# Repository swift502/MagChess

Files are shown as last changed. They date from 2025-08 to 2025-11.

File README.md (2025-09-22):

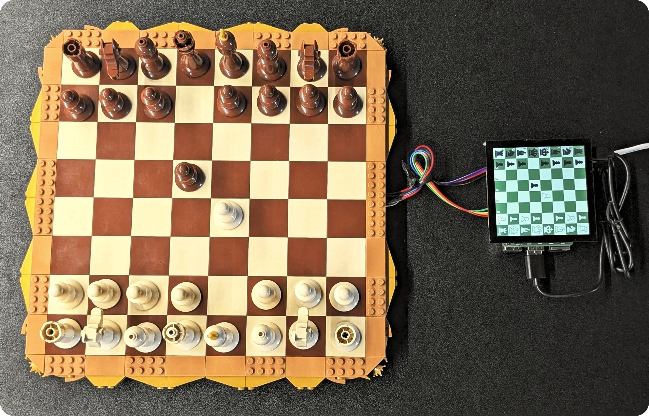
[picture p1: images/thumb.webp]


# MagChess

Magnetic chess game interpreter and PGN exporter for the Lego [Traditional Chess Set](https://www.lego.com/en-cz/product/traditional-chess-set-40719). Python app for the Raspberry Pi, and an Astro website to serve the results and show a leaderboard.

## App

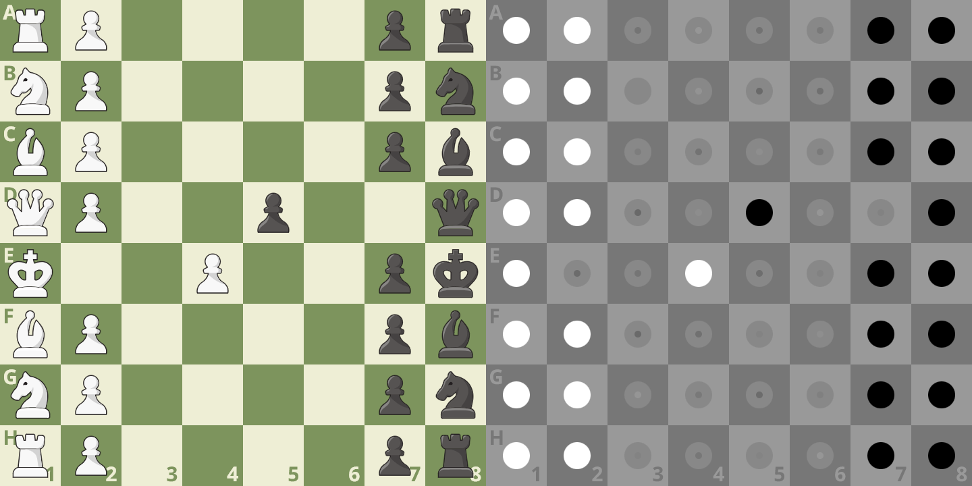
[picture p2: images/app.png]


**Setup:**

```bash
rpi_install.sh
```

After installation, a reboot is required for the I2C data rate change to take effect.

**Run:**

```bash
rpi_run.sh
```

### Desktop shortcut

```ini
[Desktop Entry]
Type=Application
Name=MagChess
Icon=/home/pi/Documents/Github/MagChess/app/assets/icon.ico
Exec=/home/pi/Documents/Github/MagChess/app/rpi_run.sh
Category=Game
```

### Autostart config

```bash
mkdir -p ~/.config/autostart
nano ~/.config/autostart/magchess.desktop
```

## Hardware

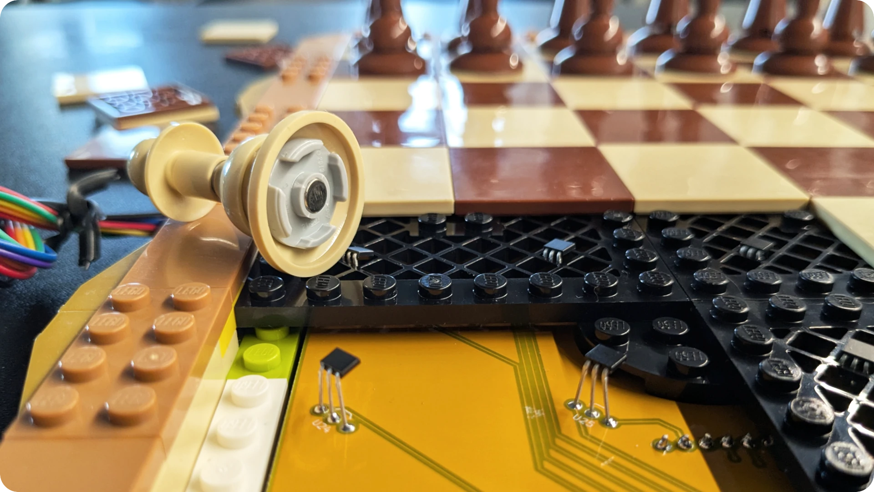
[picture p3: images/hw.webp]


The PCB in `kicad/pcb` is designed to fit a modified underside of the lego chessboard construction found in `bricklink_studio/chessboard.io`.

The PCB needs the following components soldered onto it:

- 64x SS49E
- 4x CD74HC4067
- ADS1015
- MP1584EN

Each lego chess piece has to be fitted with a magnet on the bottom. Round 5x2mm magnets happen to fit perfectly into the bottom of each piece.

Magnet polarity is important, if white pieces read magnetic north, black pieces should be flipped and read south. The hall sensors will then read colors as positive/negative voltage, which gives the app enough information to interpret chess moves correctly.

The app should be installed on a Raspberry Pi. The chessboard draws 5V and GND from the pi. Data pins are the I2C SDA and SCL pins and four mux selection pins, by default D21, D20, D16 and D12. An estimated 800mA is drawn by the hall sensors when powered.

## Scoreboard

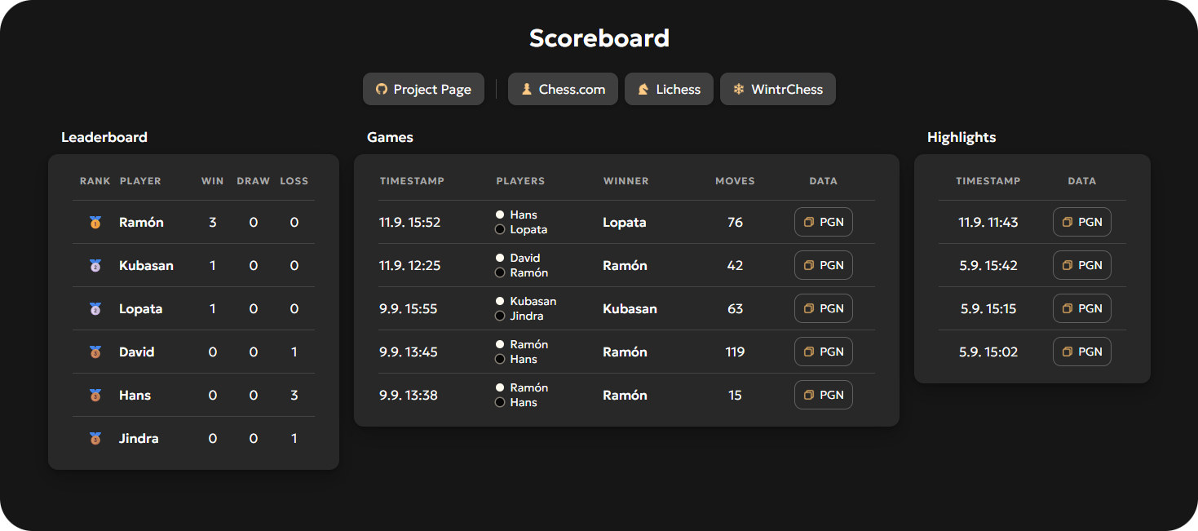
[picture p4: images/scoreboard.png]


<div align="center">
    <a href="https://swift502.github.io/MagChess">https://swift502.github.io/MagChess</a>
</div>
<br>

Astro website showing a leaderboard and a PGN archive. Deployed via GitHub Pages.

### Build notes

```bash
npm install
npm run dev
npm run build
```

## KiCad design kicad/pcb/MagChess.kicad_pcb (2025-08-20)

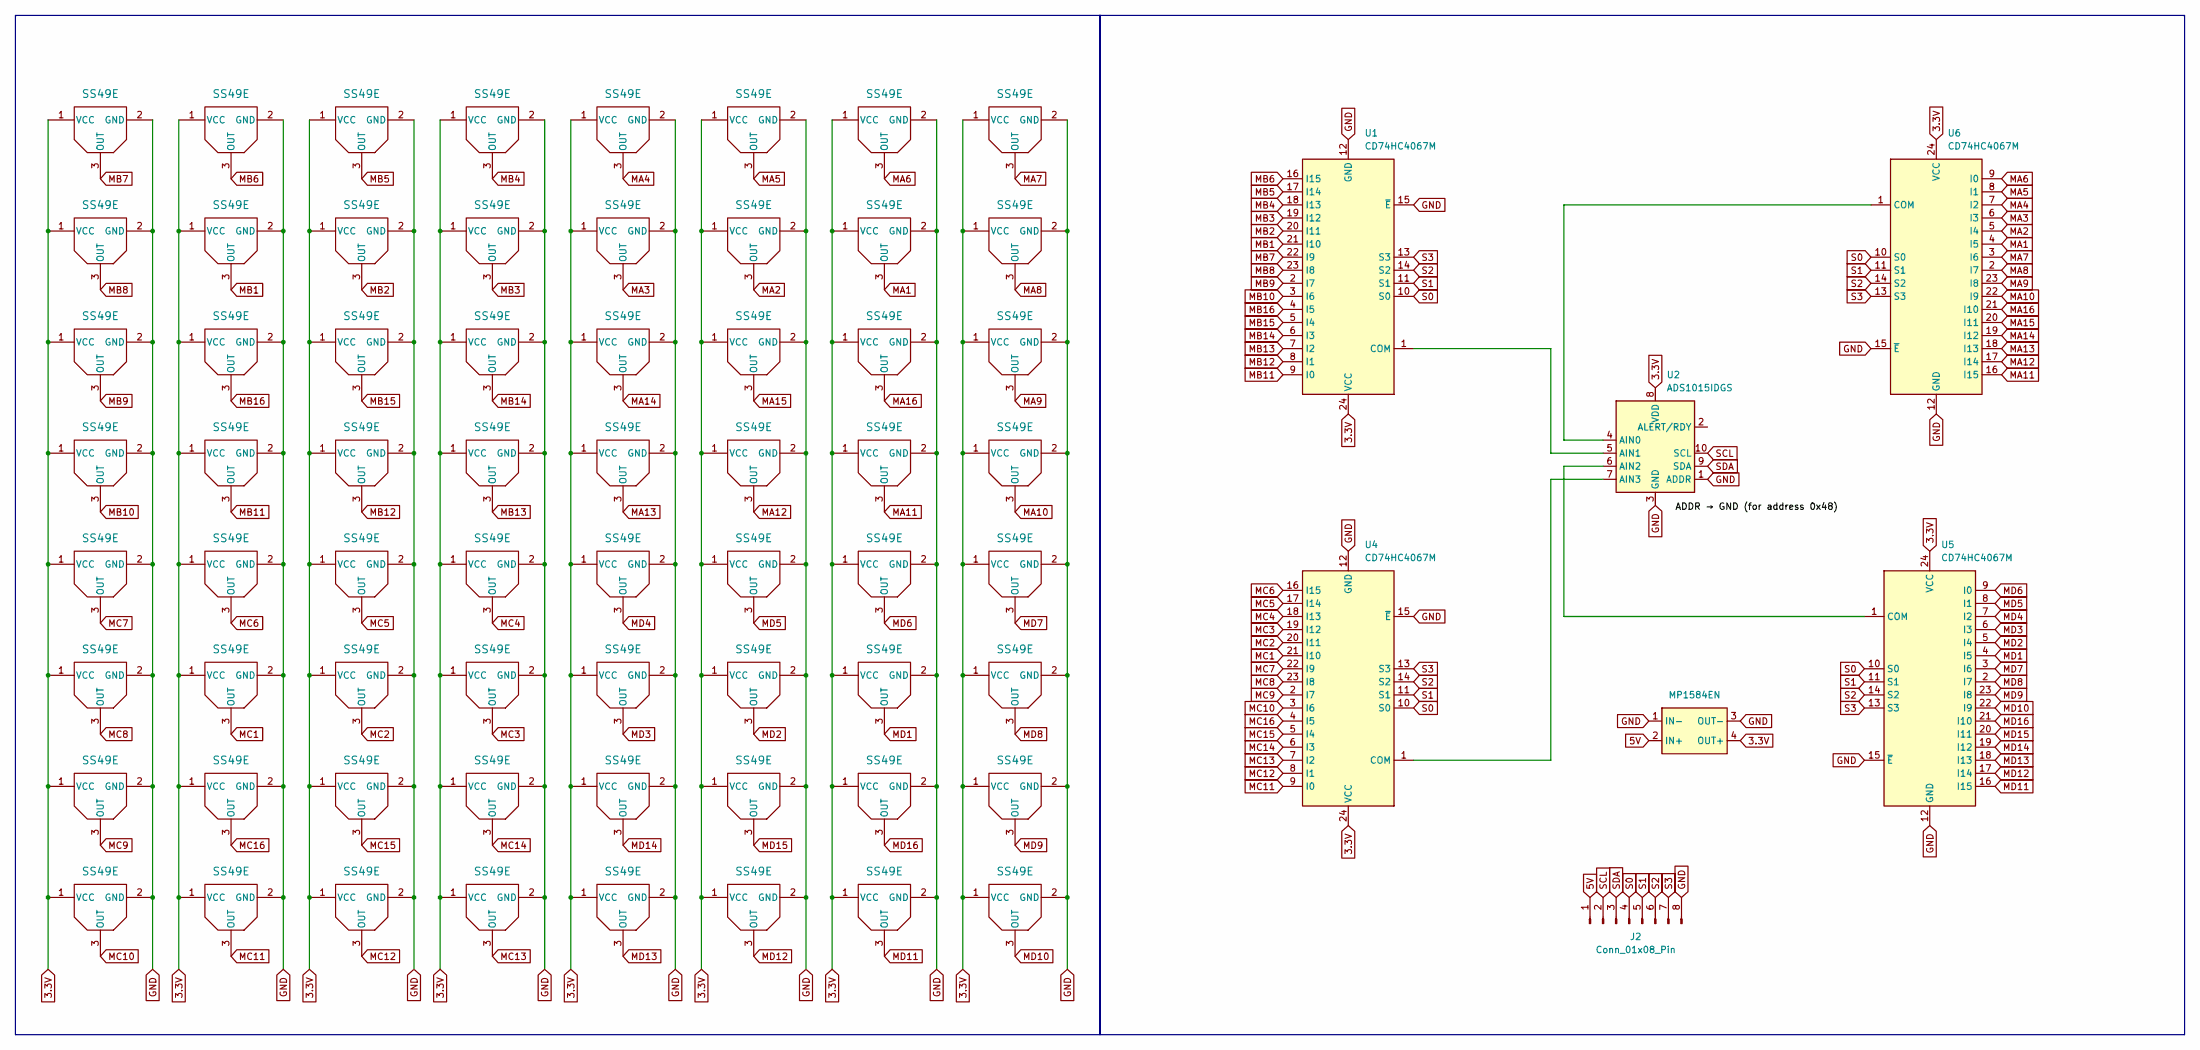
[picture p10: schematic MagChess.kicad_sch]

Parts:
J2: Conn_01x08_Pin; PinHeader_1x08_P2.54mm_Vertical
U1, U4, U5, U6: CD74HC4067M; CD74HC4067
U2: ADS1015IDGS; ADS1015
U3: MP1584EN; MP1584
U12, U13, U14, U15, U16, U17, U18, U19, U20, U21, U22, U23, U24, U25, U26, U27, U28, U29, U30, U31, U32, U33, U34, U35, U36, U37, U38, U39, U40, U41, U42, U43, U44, U45, U46, U47, U48, U49, U50, U51, U52, U53, U54, U55, U56, U57, U58, U59, U60, U61, U62, U63, U64, U65, U66, U67, U68, U69, U70, U71, U72, U73, U74, U75: SS49E

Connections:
3.3V: U1.24 (VCC), U2.8 (VDD), U3.4 (OUT+), U4.24 (VCC), U5.24 (VCC), U6.24 (VCC), U12.1 (VCC), U13.1 (VCC), U14.1 (VCC), U15.1 (VCC), U16.1 (VCC), U17.1 (VCC), U18.1 (VCC), U19.1 (VCC), U20.1 (VCC), U21.1 (VCC), U22.1 (VCC), U23.1 (VCC), U24.1 (VCC), U25.1 (VCC), U26.1 (VCC), U27.1 (VCC), U28.1 (VCC), U29.1 (VCC), U30.1 (VCC), U31.1 (VCC), U32.1 (VCC), U33.1 (VCC), U34.1 (VCC), U35.1 (VCC), U36.1 (VCC), U37.1 (VCC), U38.1 (VCC), U39.1 (VCC), U40.1 (VCC), U41.1 (VCC), U42.1 (VCC), U43.1 (VCC), U44.1 (VCC), U45.1 (VCC), U46.1 (VCC), U47.1 (VCC), U48.1 (VCC), U49.1 (VCC), U50.1 (VCC), U51.1 (VCC), U52.1 (VCC), U53.1 (VCC), U54.1 (VCC), U55.1 (VCC), U56.1 (VCC), U57.1 (VCC), U58.1 (VCC), U59.1 (VCC), U60.1 (VCC), U61.1 (VCC), U62.1 (VCC), U63.1 (VCC), U64.1 (VCC), U65.1 (VCC), U66.1 (VCC), U67.1 (VCC), U68.1 (VCC), U69.1 (VCC), U70.1 (VCC), U71.1 (VCC), U72.1 (VCC), U73.1 (VCC), U74.1 (VCC), U75.1 (VCC)
5V: J2.1, U3.2 (IN+)
GND: J2.8, U1.12 (GND), U1.15 (~E), U2.1 (ADDR), U2.3 (GND), U3.1 (IN-), U3.3 (OUT-), U4.12 (GND), U4.15 (~E), U5.12 (GND), U5.15 (~E), U6.12 (GND), U6.15 (~E), U12.2 (GND), U13.2 (GND), U14.2 (GND), U15.2 (GND), U16.2 (GND), U17.2 (GND), U18.2 (GND), U19.2 (GND), U20.2 (GND), U21.2 (GND), U22.2 (GND), U23.2 (GND), U24.2 (GND), U25.2 (GND), U26.2 (GND), U27.2 (GND), U28.2 (GND), U29.2 (GND), U30.2 (GND), U31.2 (GND), U32.2 (GND), U33.2 (GND), U34.2 (GND), U35.2 (GND), U36.2 (GND), U37.2 (GND), U38.2 (GND), U39.2 (GND), U40.2 (GND), U41.2 (GND), U42.2 (GND), U43.2 (GND), U44.2 (GND), U45.2 (GND), U46.2 (GND), U47.2 (GND), U48.2 (GND), U49.2 (GND), U50.2 (GND), U51.2 (GND), U52.2 (GND), U53.2 (GND), U54.2 (GND), U55.2 (GND), U56.2 (GND), U57.2 (GND), U58.2 (GND), U59.2 (GND), U60.2 (GND), U61.2 (GND), U62.2 (GND), U63.2 (GND), U64.2 (GND), U65.2 (GND), U66.2 (GND), U67.2 (GND), U68.2 (GND), U69.2 (GND), U70.2 (GND), U71.2 (GND), U72.2 (GND), U73.2 (GND), U74.2 (GND), U75.2 (GND)
MA1: U6.4 (I5), U21.3 (OUT)
MA2: U6.5 (I4), U31.3 (OUT)
MA3: U6.6 (I3), U32.3 (OUT)
MA4: U6.7 (I2), U29.3 (OUT)
MA5: U6.8 (I1), U28.3 (OUT)
MA6: U6.9 (I0), U20.3 (OUT)
MA7: U6.3 (I6), U12.3 (OUT)
MA8: U6.2 (I7), U13.3 (OUT)
MA9: U6.23 (I8), U14.3 (OUT)
MA10: U6.22 (I9), U15.3 (OUT)
MA11: U6.16 (I15), U23.3 (OUT)
MA12: U6.17 (I14), U37.3 (OUT)
MA13: U6.18 (I13), U38.3 (OUT)
MA14: U6.19 (I12), U35.3 (OUT)
MA15: U6.20 (I11), U34.3 (OUT)
MA16: U6.21 (I10), U22.3 (OUT)
MB1: U1.21 (I10), U56.3 (OUT)
MB2: U1.20 (I11), U55.3 (OUT)
MB3: U1.19 (I12), U33.3 (OUT)
MB4: U1.18 (I13), U30.3 (OUT)
MB5: U1.17 (I14), U52.3 (OUT)
MB6: U1.16 (I15), U53.3 (OUT)
MB7: U1.22 (I9), U54.3 (OUT)
MB8: U1.23 (I8), U57.3 (OUT)
MB9: U1.2 (I7), U60.3 (OUT)
MB10: U1.3 (I6), U63.3 (OUT)
MB11: U1.9 (I0), U62.3 (OUT)
MB12: U1.8 (I1), U61.3 (OUT)
MB13: U1.7 (I2), U39.3 (OUT)
MB14: U1.6 (I3), U36.3 (OUT)
MB15: U1.5 (I4), U58.3 (OUT)
MB16: U1.4 (I5), U59.3 (OUT)
MC1: U4.21 (I10), U68.3 (OUT)
MC2: U4.20 (I11), U67.3 (OUT)
MC3: U4.19 (I12), U45.3 (OUT)
MC4: U4.18 (I13), U42.3 (OUT)
MC5: U4.17 (I14), U64.3 (OUT)
MC6: U4.16 (I15), U65.3 (OUT)
MC7: U4.22 (I9), U66.3 (OUT)
MC8: U4.23 (I8), U69.3 (OUT)
MC9: U4.2 (I7), U72.3 (OUT)
MC10: U4.3 (I6), U75.3 (OUT)
MC11: U4.9 (I0), U74.3 (OUT)
MC12: U4.8 (I1), U73.3 (OUT)
MC13: U4.7 (I2), U51.3 (OUT)
MC14: U4.6 (I3), U48.3 (OUT)
MC15: U4.5 (I4), U70.3 (OUT)
MC16: U4.4 (I5), U71.3 (OUT)
MD1: U5.4 (I5), U25.3 (OUT)
MD2: U5.5 (I4), U43.3 (OUT)
MD3: U5.6 (I3), U44.3 (OUT)
MD4: U5.7 (I2), U41.3 (OUT)
MD5: U5.8 (I1), U40.3 (OUT)
MD6: U5.9 (I0), U24.3 (OUT)
MD7: U5.3 (I6), U16.3 (OUT)
MD8: U5.2 (I7), U17.3 (OUT)
MD9: U5.23 (I8), U18.3 (OUT)
MD10: U5.22 (I9), U19.3 (OUT)
MD11: U5.16 (I15), U27.3 (OUT)
MD12: U5.17 (I14), U49.3 (OUT)
MD13: U5.18 (I13), U50.3 (OUT)
MD14: U5.19 (I12), U47.3 (OUT)
MD15: U5.20 (I11), U46.3 (OUT)
MD16: U5.21 (I10), U26.3 (OUT)
unnamed: U1.1 (COM), U2.5 (AIN1)
unnamed: U2.4 (AIN0), U6.1 (COM)
unnamed: U2.6 (AIN2), U5.1 (COM)
unnamed: U2.7 (AIN3), U4.1 (COM)
S0: J2.4, U1.10 (S0), U4.10 (S0), U5.10 (S0), U6.10 (S0)
S1: J2.5, U1.11 (S1), U4.11 (S1), U5.11 (S1), U6.11 (S1)
S2: J2.6, U1.14 (S2), U4.14 (S2), U5.14 (S2), U6.14 (S2)
S3: J2.7, U1.13 (S3), U4.13 (S3), U5.13 (S3), U6.13 (S3)
SCL: J2.2, U2.10 (SCL)
SDA: J2.3, U2.9 (SDA)

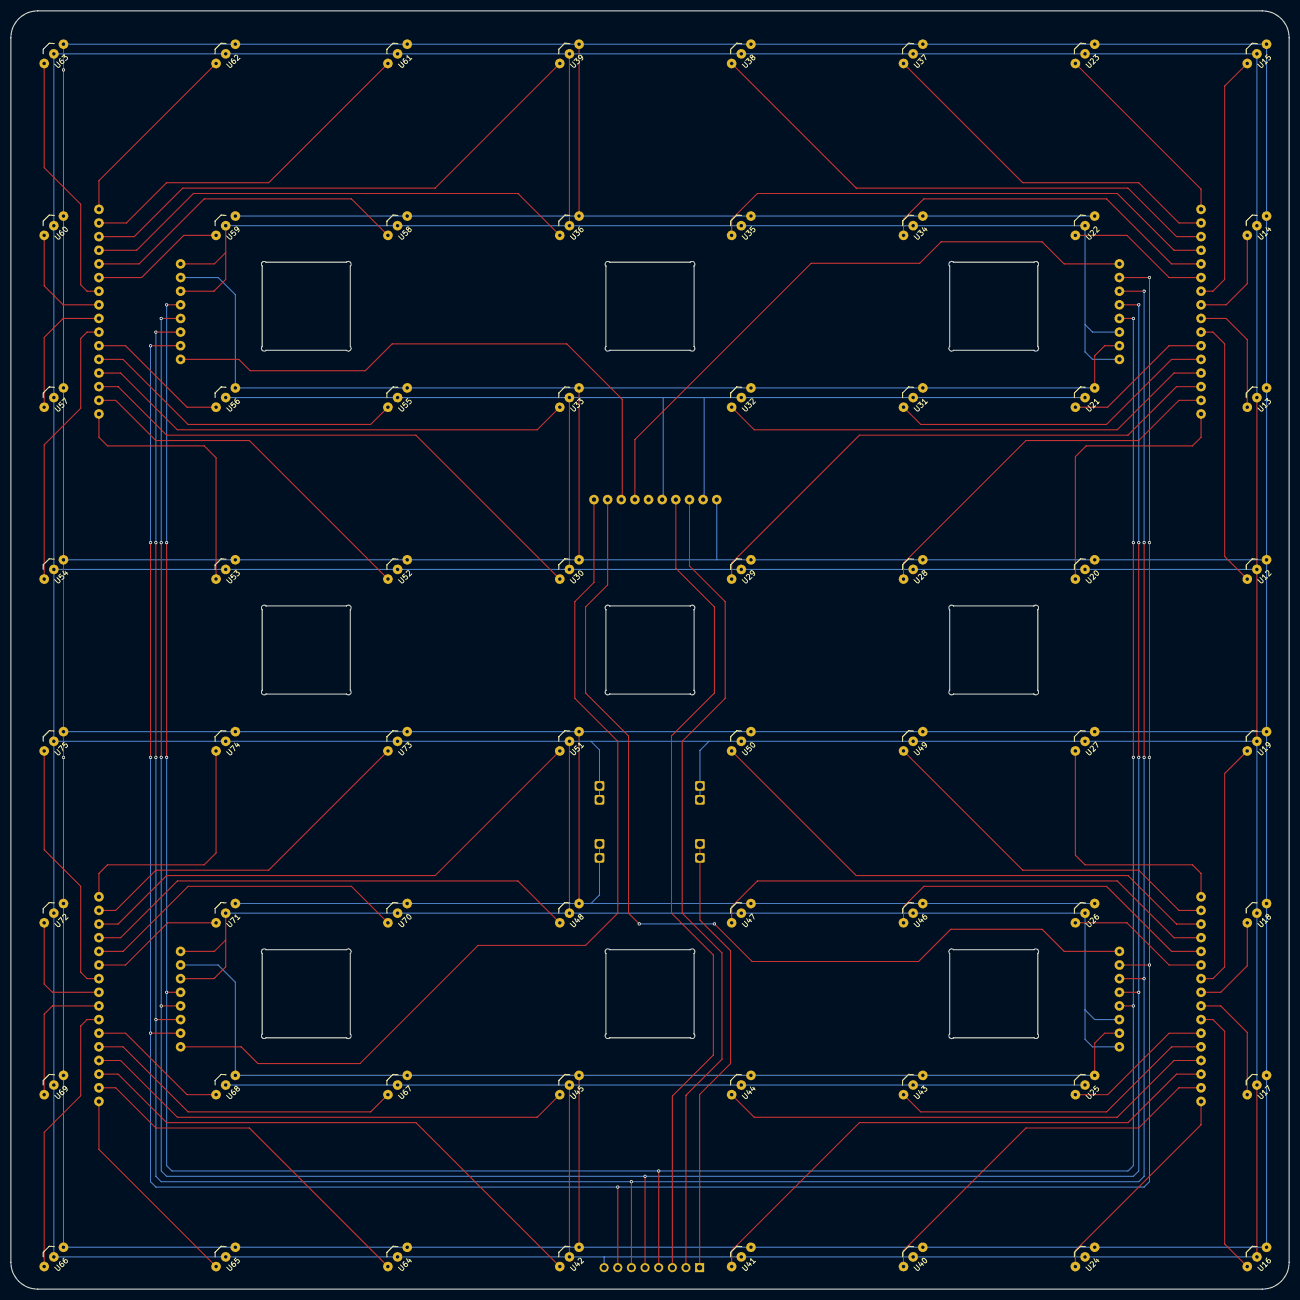
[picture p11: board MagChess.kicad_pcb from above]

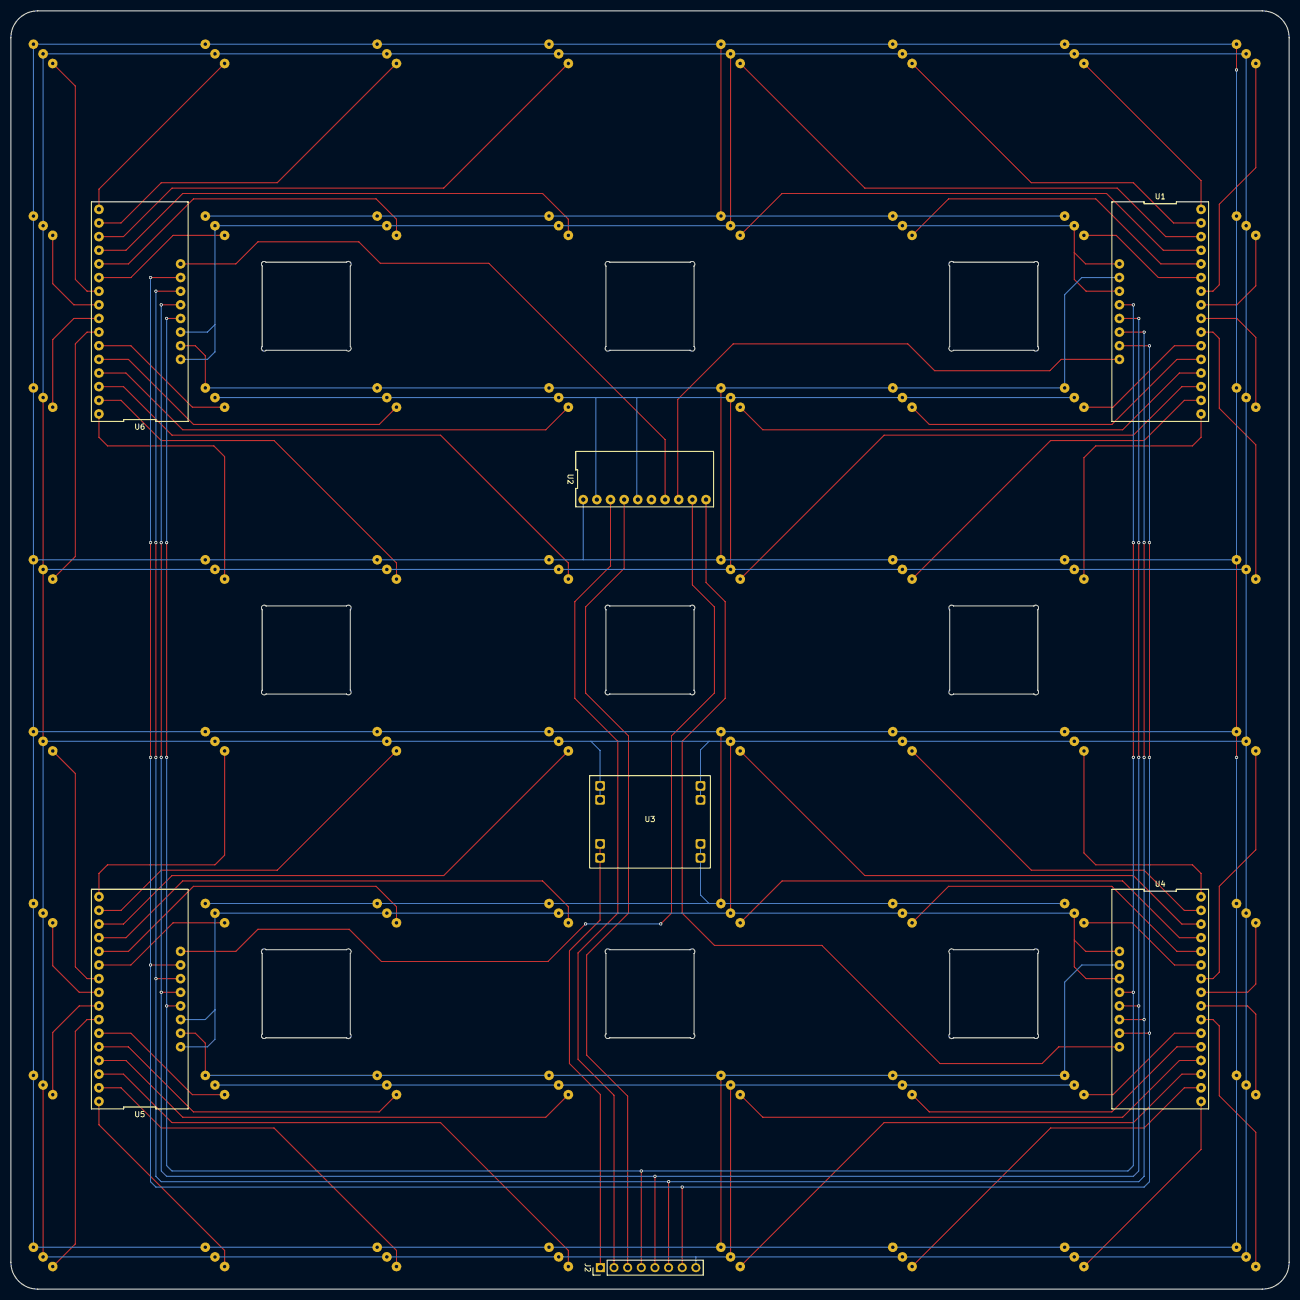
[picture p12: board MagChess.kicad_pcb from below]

Board: 2 copper layers, 238.0 x 238.0 mm, 71 parts (7 on the bottom side), 77 nets.

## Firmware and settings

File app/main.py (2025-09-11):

import flet as ft

from chessboard import Chessboard
from constants import DEV_LAYOUT, RPI
from ui_instance import MagChessUI
from utilities import asset_path

def on_key(e: ft.KeyboardEvent, page: ft.Page):
    if e.key == "Escape":
        page.window.close()
    if e.key == "F11":
        page.window.full_screen = not page.window.full_screen

async def main(page: ft.Page):
    page.title = "MagChess"
    page.window.icon = asset_path("icon.ico")
    page.window.width = 720
    page.window.height = 720
    page.window.frameless = True
    if DEV_LAYOUT:
        page.window.width = page.window.width * 2
    if RPI:
        page.window.full_screen = True
    page.padding = 0
    page.spacing = 0
    page.on_keyboard_event = lambda e: on_key(e, page)
    page.theme_mode = ft.ThemeMode.DARK
    page.fonts = {
        "Noto Sans": asset_path("fonts/NotoSans-Bold.ttf"),
        "Noto Sans Info": asset_path("fonts/NotoSans-SemiBold.ttf"),
        "Noto Sans Dialog": asset_path("fonts/NotoSans-Regular.ttf"),
    }

    # App
    ui = MagChessUI(page)
    chessboard = Chessboard(page, ui)
    ui.chessboard = chessboard

    if RPI:
        from sensors_hw import HWSensors
        sensors = HWSensors(chessboard.update_sensor_value, ui)
    else:
        from sensors_sw import SWSensors
        sensors = SWSensors(chessboard.update_sensor_value, flipped=False)
        ui.sensor_interaction(sensors.on_sensor_click)

    page.run_task(sensors.sensor_reading_loop)
    page.run_task(chessboard.update)

if __name__ == "__main__":
    ft.app(target=main)

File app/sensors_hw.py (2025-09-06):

import asyncio
from typing import Callable
import board
import busio
import digitalio
import adafruit_ads1x15.ads1015 as ADS
from adafruit_ads1x15.analog_in import AnalogIn

from ui_instance import MagChessUI

class HWSensors():
    # ADC input + corresponding multiplexer input
    # Mapped to a chessboard cell coordinate
    sensor_mapping = {
        "a0m00": (4,1), "a1m00": (7,6), "a2m00": (0,1), "a3m00": (3,6),
        "a0m01": (4,2), "a1m01": (7,5), "a2m01": (0,2), "a3m01": (3,5),
        "a0m02": (4,3), "a1m02": (7,4), "a2m02": (0,3), "a3m02": (3,4),
        "a0m03": (5,3), "a1m03": (6,4), "a2m03": (1,3), "a3m03": (2,4),
        "a0m04": (5,2), "a1m04": (6,5), "a2m04": (1,2), "a3m04": (2,5),
        "a0m05": (5,1), "a1m05": (6,6), "a2m05": (1,1), "a3m05": (2,6),
        "a0m06": (4,0), "a1m06": (7,7), "a2m06": (0,0), "a3m06": (3,7),
        "a0m07": (5,0), "a1m07": (6,7), "a2m07": (1,0), "a3m07": (2,7),
        "a0m08": (6,0), "a1m08": (5,7), "a2m08": (2,0), "a3m08": (1,7),
        "a0m09": (7,0), "a1m09": (4,7), "a2m09": (3,0), "a3m09": (0,7),
        "a0m10": (6,1), "a1m10": (5,6), "a2m10": (2,1), "a3m10": (1,6),
        "a0m11": (6,2), "a1m11": (5,5), "a2m11": (2,2), "a3m11": (1,5),
        "a0m12": (6,3), "a1m12": (5,4), "a2m12": (2,3), "a3m12": (1,4),
        "a0m13": (7,3), "a1m13": (4,4), "a2m13": (3,3), "a3m13": (0,4),
        "a0m14": (7,2), "a1m14": (4,5), "a2m14": (3,2), "a3m14": (0,5),
        "a0m15": (7,1), "a1m15": (4,6), "a2m15": (3,1), "a3m15": (0,6),
    }

    init_fail: bool = False

    def __init__(self, on_sensor_reading: Callable[[tuple[int, int], int], None], ui: MagChessUI | None = None):
        self.on_sensor_reading = on_sensor_reading

        # I2C
        try:
            i2c = busio.I2C(board.SCL, board.SDA)
            ads = ADS.ADS1015(i2c)
            ads.data_rate = 3300
        except Exception:
            if ui:
                ui.board_state_error("Chessboard connection not found.")
            self.init_fail = True
            return

        # Channels
        self.channels = [
            AnalogIn(ads, ADS.P0),
            AnalogIn(ads, ADS.P1),
            AnalogIn(ads, ADS.P2),
            AnalogIn(ads, ADS.P3),
        ]

        # Selection
        self.sel_pins: list[digitalio.DigitalInOut] = []
        for pin in (board.D21, board.D20, board.D16, board.D12):
            p = digitalio.DigitalInOut(pin)
            p.direction = digitalio.Direction.OUTPUT
            p.value = False
            self.sel_pins.append(p)

    async def sensor_reading_loop(self):
        if self.init_fail:
            return

        while True:
            for mul_id in range(16):
                self.set_aselect(mul_id)
                await asyncio.sleep(0.001)

                for adc_id in range(4):
                    mapping = self.sensor_mapping[f"a{adc_id}m{mul_id:02}"]
                    self.on_sensor_reading(mapping, self.channels[adc_id].value)

    def set_aselect(self, n: int) -> None:
        for bit, p in enumerate(self.sel_pins):
            p.value = bool((n >> bit) & 0x1)

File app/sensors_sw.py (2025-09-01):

import asyncio
import random
from typing import Callable

from constants import SENSOR_CALIBRATION_DATA, SENSOR_TRIGGER_DELTA, SENSOR_SIM_NOISE

class SWSensorObject:
    def __init__(self, coords: tuple[int, int], state: int):
        self.ref_value = SENSOR_CALIBRATION_DATA[str(coords)]
        self.state = state

    def get_value(self):
        if self.state == 1:
            return self.ref_value - 2 * SENSOR_TRIGGER_DELTA + self.get_noise()
        elif self.state == 3:
            return self.ref_value + 2 * SENSOR_TRIGGER_DELTA + self.get_noise()
        else:
            return self.ref_value + self.get_noise()

    def get_noise(self):
        return random.randint(-SENSOR_SIM_NOISE, SENSOR_SIM_NOISE)

    def set_state(self, state: int):
        self.state = state

class SWSensors():
    sensors: dict[tuple[int, int], SWSensorObject]

    def __init__(self, on_sensor_reading: Callable[[tuple[int, int], int], None], flipped: bool = False):
        self.sensors = {}
        self.on_sensor_reading = on_sensor_reading

        for co_letter in range(8):
            for co_number in range(8):
                coords = (co_letter, co_number)
                state = 0
                if co_number == 0 or co_number == 1:
                    state = 3 if flipped else 1
                if co_number == 6 or co_number == 7:
                    state = 1 if flipped else 3
                self.sensors[coords] = SWSensorObject(coords, state)

    async def sensor_reading_loop(self):
        while True:
            for key, sensor in self.sensors.items():
                self.on_sensor_reading(key, sensor.get_value())

            await asyncio.sleep(1/6)

    def on_sensor_click(self, co_letter: int, co_number: int):
        state = self.sensors[(co_letter, co_number)].state
        state += 1
        if state == 4:
            state = 0
        self.sensors[(co_letter, co_number)].set_state(state)

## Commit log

2025-08-14 brick link studio chess board
2025-08-15 sensor connections
    [Chess.kicad_sch]
2025-08-15 SS49E footprint
2025-08-15 MP1584 2
    [Chess.kicad_sch]
2025-08-15 errors fix
    [Chess.kicad_pcb]
2025-08-15 routes 1
    [Chess.kicad_pcb]
2025-08-16 routes 2
    [Chess.kicad_pcb, Chess.kicad_sch]
2025-08-16 fill zone
    [Chess.kicad_pcb]
2025-08-16 routing v2
    [Chess.kicad_pcb, Chess.kicad_sch]
2025-08-16 input port
    [Chess.kicad_pcb, Chess.kicad_sch]
2025-08-16 PSU remake
    [Chess.kicad_pcb]
2025-08-16 sensor silkscreen footprint
    [Chess.kicad_pcb]
2025-08-17 board 2
2025-08-19 ADC footprint
    [Chess.kicad_pcb]
2025-08-20 parts update
    [MagChess.kicad_pcb, MagChess.kicad_sch]
2025-08-22 replay button style
2025-08-22 esc exit
2025-08-22 sensors, debug mode
2025-08-22 sensor rewrite
2025-08-22 sensor appearance
2025-08-23 sensor input
2025-08-24 hw sensor preparation
2025-08-24 sensor state strings
2025-08-24 sensor interaction
2025-08-26 async sensors 1
2025-08-26 async sensors 2
2025-08-27 replay button refresh
2025-08-28 advantage bar spring
2025-08-29 snackbar color, sensor data None checking
2025-08-31 calibration 1
2025-08-31 calibration 2
2025-08-31 show_state fix, page update optimization
    [chessboard.py, piece.py, ui_instance.py]
2025-08-31 calibration SPS
2025-09-01 calibration flag
2025-09-01 calibration fix
2025-09-02 sensor speed
2025-09-11 git push raise if error
    [ui_builder.py]
